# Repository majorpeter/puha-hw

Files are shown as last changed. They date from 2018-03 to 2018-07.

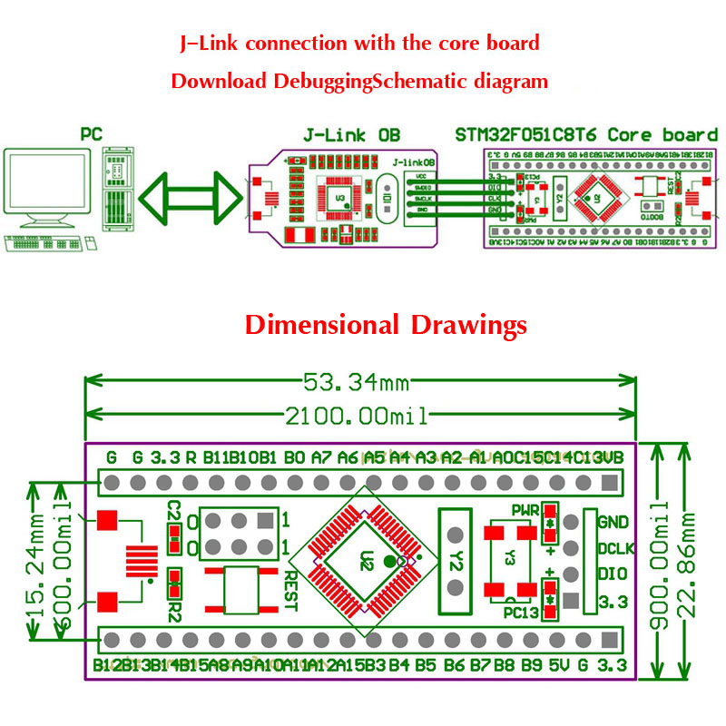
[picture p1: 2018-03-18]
datasheet/STM32F103C8T6_evb/STM32F103C8T6_evb-drawing.jpg

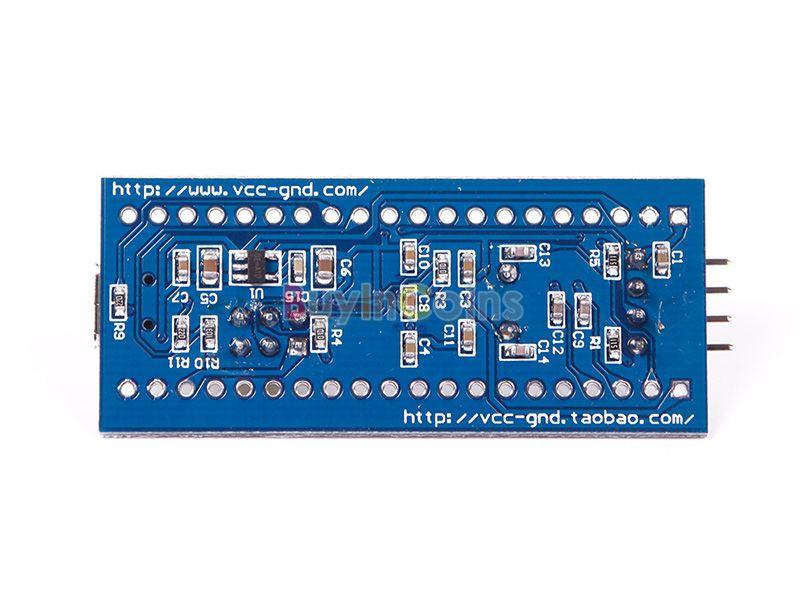
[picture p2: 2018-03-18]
datasheet/STM32F103C8T6_evb/m2kctg2a5.jpg

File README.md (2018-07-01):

# `Pretty Universal Home Automation` hardware specification

## Design goals

Create an embedded device that is:

* controllable via wifi or USB,
* controls things such as lighting,
* provides measurements (e.g. temperature, humidity)
* remotely upgradeable

## Components

### Core Components

* STM32F103C8T6 Evaluation Board
* ESP-01 wifi module
* 5V power supply

### Optional/Supported Components

* WS2812B programmable RGB LED strip
* HTU21D Temperature & Humidity sensor
* HC-SR501 PIR motion sensor
* Knightbright KPS-3227SP1C ambient light photo sensor

## STM32 pinout

| Pin function | STM32 Pin | Connected to |
|---|---|---|
| USART1 RX | PA10 | ESP-01 TXD |
| USART1 TX | PA9 | ESP-01 RXD |
| BOOT0 (=1) | - | ESP-01 GPIO2 |
| BOOT1 (=0) | - | _GND_ |
| NRST | - | ESP-01 GPIO0\* |
| I2C1 SDA | PB7 | HTU21D SDA |
| I2C1 SCL | PB6 | HTU21D SCL |
| GPIOB12 | PB12 | WS2812B DATA IN |
| EXTI1 | PB1 | HC-SR501 Out |
| ADC12_IN1 | PA1 | KPS Out |

\*: The STM32 also controls its `NRST` pin when it's being reset from software (or by using a debugger), so a series resistor is required between the ESP and the STM. The pin is pulled up with 10k on the STM32 board, so a ~2kOhm series resistor is sufficient.

The serial communication between the ESP-01 and the STM32 uses the baud rate of `460800` in `8N1` format.

## Features

### Remote firmware upgrade

#### STM32F1

The embedded bootloader (DFU) can be used. USART1, BOOT0 and NRST must be connected to the ESP module. Bootloader is activated by "Pattern 1".

BOOT0 must not be pulled high by default, NRST pull-up is O.K.
Series resistors should be included between STM and ESP pins.

##### Boot configuration

| BOOT1 | BOOT0 | Mode |
|:-----:|:-----:|:---|
| x | 0 | Main Flash memory |
| 0 | 1 | System memory |
| 1 | 1 | Embedded SRAM |

##### Notes
* 512 byte starting from address 0x20000000 are used by the bootloader firmware.
* 2 Kbyte starting from address 0x1FFFF000 contain the bootloader firmware.

##### See also
* [AN2606: STM32 microcontroller system memory boot mode](http://www.st.com/content/ccc/resource/technical/document/application_note/b9/9b/16/3a/12/1e/40/0c/CD00167594.pdf/files/CD00167594.pdf/jcr:content/translations/en.CD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)

#### ESP-01

Using the [esp-link firmware](https://github.com/jeelabs/esp-link) on the device makes remote firmware upgrade possible from the web interface. Unfortunately that only works on the ESP-12, with the large flash, and not on the ESP-01.

##### Boot configuration

GPIO0 and GPIO2 weak pull-up required. CH_PD must be pulled high to operate.

#### Controlling the STM32 bootloader from the ESP-01

To control the NRST and BOOT0 pins, one must send Telnet commands to the device (manually control the RTS and DTR signals). The [telnet_serial_interface](https://github.com/majorpeter/telnet_serial_interface/) project can be used to send those commands. For example (assume the device is available at IP `192.168.0.211`):

* Reset MCU
```
./telnet_serial.py 192.168.0.211 dtr 1
./telnet_serial.py 192.168.0.211 dtr 0
```

* Switch to Application (boot from main flash)
```
./telnet_serial.py 192.168.0.211 rts 0
./telnet_serial.py 192.168.0.211 dtr 1
./telnet_serial.py 192.168.0.211 dtr 0
```

* Switch to DFU (boot from system memory)
```
./telnet_serial.py 192.168.0.211 rts 1
./telnet_serial.py 192.168.0.211 dtr 1
./telnet_serial.py 192.168.0.211 dtr 0
```

### Ambient light sensor feature

According to [wikipedia](https://en.wikipedia.org/wiki/Lux), illuminance in the kitchen should always be under `80 lx`, the living room should be around `300-400 lx`.

The KPS's maximal collector current is `20 mA`, which would be 20 000 lx. That can be achieved on a bright day, or on direct sunlight (collector current must be limited). V_CE saturation voltage is `0.4 V` at 10 000 lx.

#### Implementation

The STM32's ADC can be configured in many ways. The input impedance depends on sampling time, max 50 kOhm for 4 us sampling. Voltage range depends on `VDDA`, which is connected to **3V3** on the Evaluation Board.

Connect C to 3.3 V power supply, connect E to a series resistor that is connected to GND. The voltage measured on E will be a function of R value and illuminance.

The resistor value should be above 165 Ohm (allows 20 mA at 3.3 V) and under 3.3 kOhm (allows 1 mA ~ 1000 lx). I chose 1 kOhm to simplify calculations. `1 kOhm << 50 kOhm` (input impedance can be ignored).

### Temperature and Humidity measurement

The HTU21D sensor is attached to the I2C1 peripheral of the MCU. The sensor's 7-bit address is `0x40` (`0x80` with the R/W bit). After powering up the device, a soft reset is recommended (`0xFE`).

The sensor can be used in _hold master_ and _no hold master_ modes. The hold master mode means that the SCL line is blocked while measuring (clock stretch). This can be used in this application since there are no other devices on the bus. Humidity measurement takes 16 ms (12 bits), temperature measurement is 50 ms (14 bits). Resolution can be set in the `User Register`.

Measurements can be read with or without an 8-bit CRC.

### Motion Sensor

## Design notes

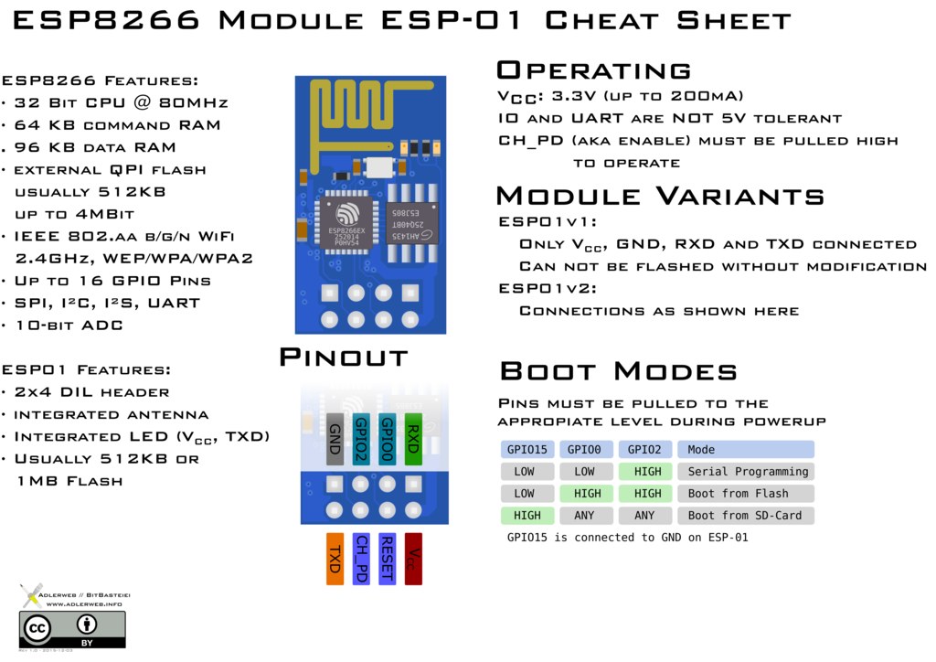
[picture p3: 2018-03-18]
datasheet/esp8266_esp_01_module_pinout_diagram_cheat_sheet_by_adlerweb-d9iwm7a.png

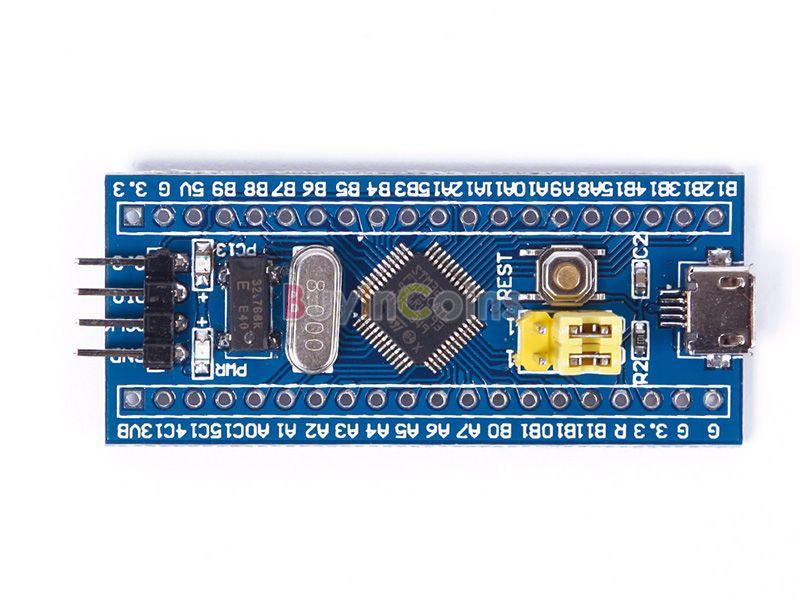
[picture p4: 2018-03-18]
datasheet/STM32F103C8T6_evb/m2kctepd8.jpg

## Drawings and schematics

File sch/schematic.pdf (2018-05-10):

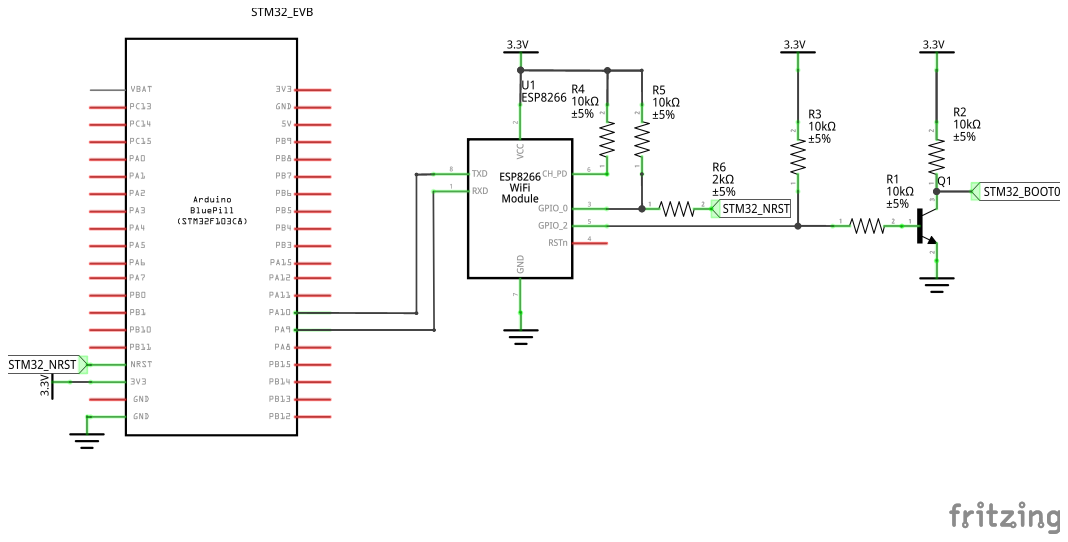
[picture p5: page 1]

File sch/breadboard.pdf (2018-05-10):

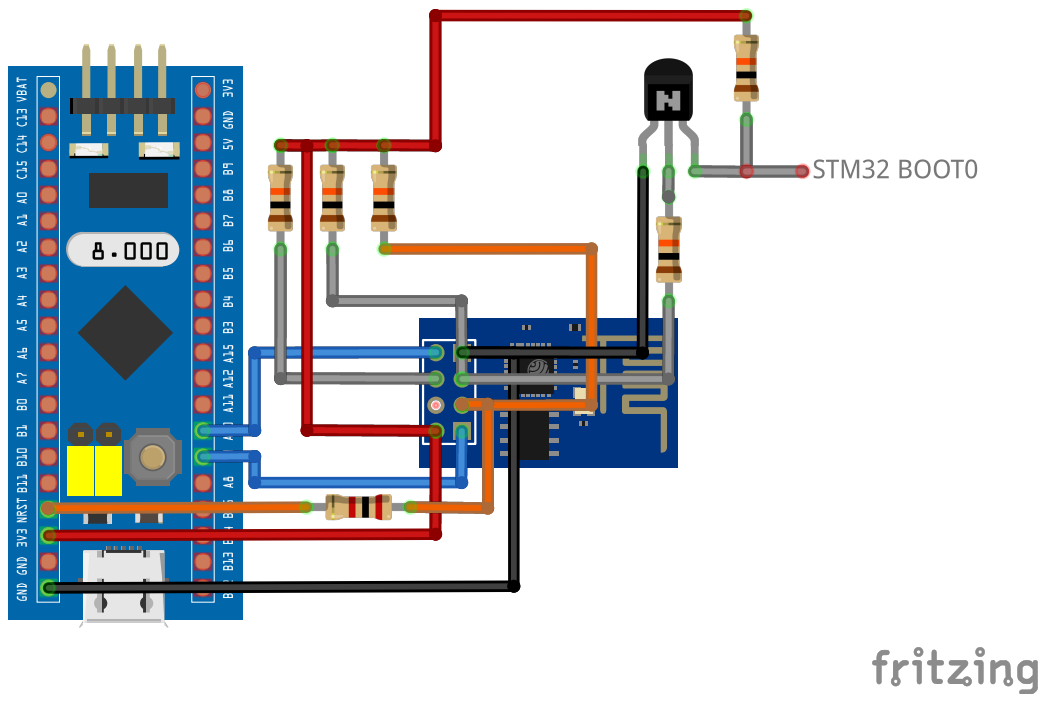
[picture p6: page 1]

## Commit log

2018-03-18 added STM32F1 datasheets, manuals
2018-04-28 created basic schematic in fritzing
    [schematic.fzz]
2018-04-28 updated pinout, added section about HTU sensor
2018-05-07 created breadboard 'schematic' and export
    [schematic.fzz]
2018-05-07 added label to STM32 BOOT0
    [schematic.fzz]
2018-05-10 added NRST series resistor to SCH, and documentation
    [schematic.fzz]
2018-05-10 fixed base resistor value for inverting circuit
    [schematic.fzz]
2018-05-14 added GPIOB12 as WS2812B output
    [schematic.fzz]
2018-05-16 added GPIOA1 as KPS ADC in, updated emitter resistor value
2018-07-01 added section on STM32 boot configuration via ESP pins
2018-08-08 added HC-SR501 sensor to schematic
    [schematic.fzz]
